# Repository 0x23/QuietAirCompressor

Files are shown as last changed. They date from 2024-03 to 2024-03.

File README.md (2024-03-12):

# Compact and Quiet Air Compressor
A small and quiet air compressor design using 3D printed parts where possible.<br>
CAD models are available as Fusion360 Project and as STEP file.

<br><br>

<div style="display: flex;">
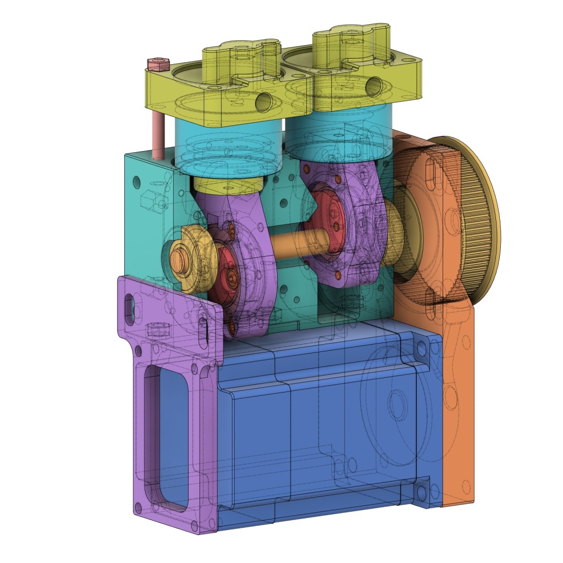
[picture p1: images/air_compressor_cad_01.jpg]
Air Compressor
    
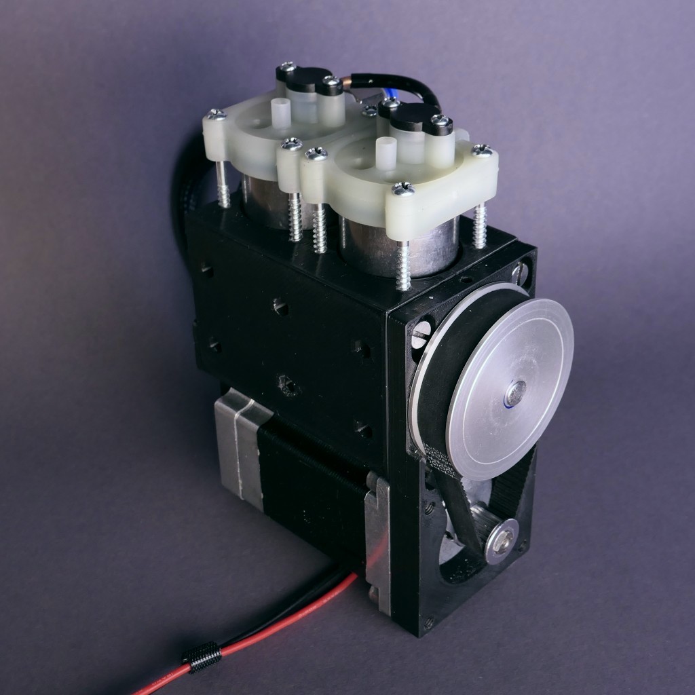
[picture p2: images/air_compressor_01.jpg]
Air Compressor CAD
    
</div>

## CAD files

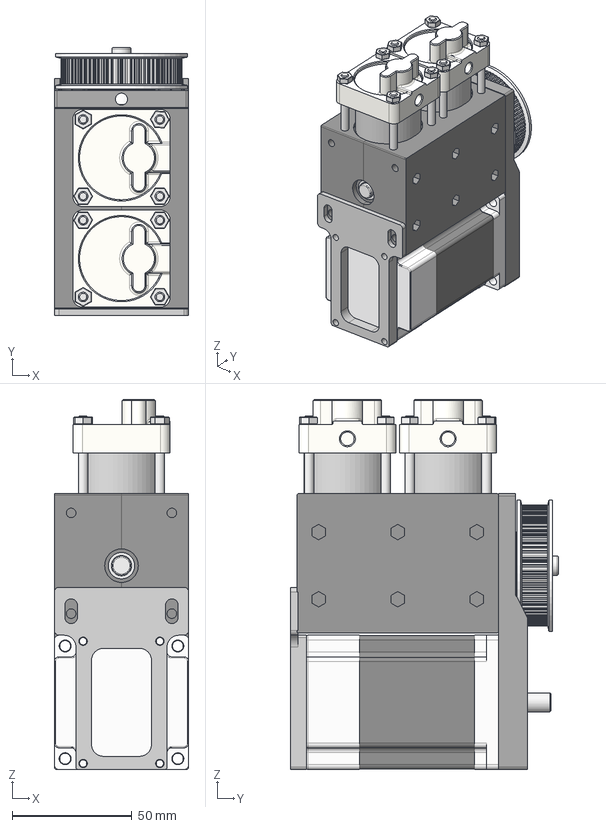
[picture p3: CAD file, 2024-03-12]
construction/AirCompressor.step
56.0 x 111.7 x 154.3 mm
CompressorBody x 2
MotorMountPlate v4
ExcenterDisk v18 x 2
DriveRod v12 x 2
Bearing_20x32x7 x 2
ShaftPin x 2
PistonHead x 2
Scre_M3x10_FlatHead x 12
PistonScrew_M3 x 2
PistonSeal x 2
Shaft
Nema23Motor
GT2Pulley_80Z
BackBracket
CylinderTensionRod x 8
Bearing_8x22x7 x 2
ValveHead x 2

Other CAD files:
construction/AirCompressor.f3d

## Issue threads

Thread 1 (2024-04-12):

BOM for non-printed parts?

Darkhand81, 2024-04-12:
Awesome project! Do you have a BOM or list of the non-printed parts, such as the quantity and dimensions of the rods, screws, etc, as well as where you sourced the pistons, cylinders, and valvehead?

0x23, 2024-04-12:
No, unfortunately I dont have a BOM but you can lookup all the dimensions
in the CAD file and if you like to contribute create a BOM for the project
yourself.
The Pistons and Cylinders were taken from this cheap car tire air
compressor:

[image: epap03-air-pump.jpg]
But be warned - the thing is really low quality (The cooling fins are fake
and made from Plastik) and it did not seal very well making it unusable for
low RPM.
Thats why I have only taken the seals and the Cylinderpipes and discarded
the rest.

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

KKobel, 2025-05-15:
I have been compiling a 'BOM' for the purchased parts.
The following are Amazon ASIN numbers:
Connecting Rod Bearing: B07TJFK68V
Main Bearing: B07FDWW9D9
Pullys and Belt: B0D97C6HFJ
M3x10: B01MFA9YEP
M3x16: B077XVVWYW
M3 Flat Washer: B015A39NCC
M4 Threadall: B09LH7PX55
M4 nuts: B0CMC61C9D
2 & 3 mm dowel pins: B0BKZND42Z

Please verify these.

What I am having trouble with is the piston seal.
Can anyone help with that.

0x23, 2025-05-15:
I used the seals and the cylinder pipes from a cheap air compressor. The seals look very similar to something like this: B07ZSB5ZFC (not correct size, just an example). Such seels are very common in hydraulics and if possible I would lean towards a softer seal material (NBR). Maybe this helps.

KKobel, 2025-05-16:
Thanks,

I found this:
https://www.mcmaster.com/9505K22/
Interestingly, the 'loaded' seals are cheaper than the 'unloaded' ones.

BTW - I am making the cylinder and head from scratch and using and external check valve on the output.
I'm using a DC brushed motor. The length is perfect. I had to modify the brackets.
I 3D printed all the parts for a fit-up.
So far, so good.

My use case is a 1.5" scale RS3 for the air brakes.

Again, thanks for a great project.
Karl

0x23, 2025-05-17:
Nice, It would be cool If you send me some pictures of compressor when its
done. Also make sure to minimize the volume between the cyclinder in the
up-position and the (external) checkvalves.
Any volume there will reduce the compression ratio and thus the maximum
pressure you can reach.

Good luck with cour project!

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

KKobel, 2025-05-18:
Thanks for the heads-up on the check valve.
I probable would have had to learn that the hard way ;)

I'll take some pictures when I get closer to finishing.

Karl
